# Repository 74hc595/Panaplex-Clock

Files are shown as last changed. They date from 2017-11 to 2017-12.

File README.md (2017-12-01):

# Panaplex Clock

This is a digital clock that uses ["Panaplex" planar gas discharge displays](http://www.tube-tester.com/sites/nixie/trade08-panaplex.htm). Panaplex displays are basically Nixie tubes with a seven-segment cathode arrangement instead of one shaped cathode per digit. And they look *awesome*. The uniform orange glow and lack of gaps between segments make them much more visually appealing than LED displays.

**[Video overview](https://youtu.be/n3AglZmtvWA)**



## Features

- 10-digit display
- Sleek, buttonless enclosure made from laser-cut walnut hardwood and acrylic
- Powered from a 5V USB charger
- Coin cell battery backup keeps time when unplugged
- Two capacitive touch sensors for user input
- Highly accurate oscillator; keeps time within ±2 parts per million (about 1 minute per year)
- 12-hour or 24-hour time display with seconds
- Weekday, month, date, and year display
- Automatic calculation of weekday from month/day/year
- Automatic leap year correction up to 2099
- Automatic daylight saving time correction (US) up to 2099
- Sleep mode: display is normally blanked, and a touch displays the time for 10 seconds before fading out
- Scheduled sleep: for each day of the week, the clock can be configured to be on contiuously, in sleep, or on during one of two configurable time ranges

## Background

"Panaplex" was a trademark of [Burroughs Corporation](http://tmsearch.uspto.gov/bin/showfield?f=doc&state=4810:w635z4.2.1), but on the internet, the term is now used generically to describe planar gas discharge displays made by other manufacturers.

The particular modules used in my clock (the SP-35x series) were introduced by [Sperry's Information Displays Division](https://en.wikipedia.org/wiki/Sperry_Corporation) in the early 1970s. I haven't found an exact date of introduction, but they are listed in this gorgeous [February 1973 Sperry Information Displays Catalog (pdf)](http://www.waynekirkwood.com/images/pdf/Sperry_Information_Displays_Catalog_1973.pdf), which implies they were introduced in 1972 or earlier. Sperry's display division was acquired by [Beckman](https://www.beckman.com/about-us/company-history/company-history-timeline) later in 1973. Babcock acquired the display division from Beckman in [1984](http://www.procureinc.com/manufacturer/Babcock_-_Microsemi/). Babcock was [acquired by Microsemi in 2008](https://www.eetimes.com/document.asp?doc_id=1169534).

These gas discharge displays (also called "plasma displays," though nowadays that term refers to TVs) were used extensively in aviation (as they are readable in bright sunlight) and in many pinball machines starting from the mid-1970s. They are still sold by [Vishay](https://www.vishay.com/displays/plasma/) at exorbitant prices.

## Hardware

I built the clock predominantly out of parts I had on hand. The electronics are constructed on four single-sided PCBs I milled with a desktop CNC machine. Here's a top view:

```
             Display Board              
     ──────────────────────────────     
 Left│                            │Right
 Wing│       ┌───────────┐        │Wing 
Board│       │Logic board│        │Board
     │       └───────────┘        │     
```

- The display board contains the Panaplex displays and the anode drive transistors
- Each "wing board" is mounted at a right angle to the display board and contains a cathode driver chip
- The logic board contains the microcontroller, real-time clock, backup battery, and high voltage power supply

Dave Jones of [EEVblog](eevblog.com) has a great series of videos ([part 1](https://www.youtube.com/watch?v=7uogKucrPks), [part 2](https://www.youtube.com/watch?v=hkbPJONJLfs), [part 3](https://www.youtube.com/watch?v=ggVu_U-CsAk&t=1123s)) where he describes how Nixie tubes can be driven with inexpensive TPIC6B595 open-drain shift registers instead of more expensive/exotic parts designed specifically for high voltage display applications. The [TPIC6B595](http://www.ti.com/product/TPIC6B595) is a cousin of the [74HC595 shift register](https://www.sparkfun.com/products/13699) (and also the namesake of my online handle) with 50V clamping diodes on its eight outputs.

Like Nixie tubes, Panaplex displays require a DC anode voltage of about 160-180 volts to operate. I'm using a [Taylor Electronics 1363](http://www.tayloredge.com/storefront/SmartNixie/PSU/index.html) high voltage supply module to step the 5V input voltage up to about 165-170V.

In addition to requiring a 5V supply, the TPIC6B595 also requires logic high inputs to be at least 4.2V. This meant that I would either have to

- use a microcontroller and real-time clock that could operate from a 5V supply, or
- add a 3.3V regulator and level translation circuitry between the microcontroller and the TPIC6B595s

I decided to go with the former to minimize part count. Looking through the microcontrollers I had on hand, I chose a [PIC16F1508](http://www.microchip.com/wwwproducts/en/PIC16F1508) with 256 bytes of RAM, 4K of ROM, and 18 I/O pins. The [ATtiny461A](http://www.microchip.com/wwwproducts/en/ATtiny461A) was the runner-up, but it only had 15 I/O pins, and the criss-crossed VCC and GND pin arrangement would have made a single-sided board layout difficult. All the ARM chips I had on hand were 3.3V parts, so an 8-bit micro was the only option.

To strike a good balance between pin usage and part count, I ganged the digit anodes together in pairs:

```  
   ┌─────────────┐   
   │   ┌─────┐   │   
┌─┬─┬─┬─┬─┬─┬─┬─┬─┬─┐
│5│4│3│2│1│1│2│3│4│5│
└─┴─┴─┴─┴─┴─┴─┴─┴─┴─┘
 │   │   └─┘   │   │ 
 │   └─────────┘   │ 
 └─────────────────┘ 
```

This arrangement only requires 5 anode drive circuits (10 transistors total and 5 I/O lines). The display is multiplexed by the microcontroller; only 2 digits are ever illuminated at a time, so we need to be able to drive 16 segments at once. For this, I used two TPIC6B595s; one to drive the cathodes of the digits on each half of the display. This led to a compact form factor where the display PCB was no larger than the displays themselves, with each TPIC6B595 on a "wing" board mounted at right angles to the display board.

My favorite real-time clock chip, the [PCF2129AT](https://www.nxp.com/docs/en/data-sheet/PCF2129.pdf), has a recommended 4.2V maximum supply voltage. Rather than push it past its specs, I Amazon Primed a [SparkFun DeadOn RTC breakout board](https://www.sparkfun.com/products/10160). The [DS3234](https://www.maximintegrated.com/en/products/digital/real-time-clocks/DS3234.html) is a highly accurate (±2ppm) clock, but golly gee whiz is it expensive. But, since this was a one-off, and Amazon Prime was the only way I was gonna get a DS3234 within 2 days, I figured it was OK to splurge.

The enclosure design is an homage to the wood-grain Heathkit clocks from the 1970s, like the [GC-1005](http://tubetime.us/index.php/2012/04/). After searching through my parts boxes for some nice buttons and coming up empty-handed, I decided to use capacitive touch pads for user input, which resulted in a very clean design with no protrusions.

## Software

The PIC16F1508 doesn't have any dedicated touch sensing hardware, but I stumbled upon Microchip Application Note [AN1298](http://ww1.microchip.com/downloads/en/AppNotes/01298A.pdf) which describes a technique that uses the built-in analog-to-digital converter and requires no external components. I still don't fully understand how it works (capacitive touch sensing is serious black magic) but it does the job!

Microchip has another app note, [AN1334](http://ww1.microchip.com/downloads/en/AppNotes/00001334B.pdf), that describes a lot of great hardware and software techniques for implementing capacitive touch. By sampling the touch sensor every 64 microseconds and using the slew-rate-limiting algorithm described in that document, I was able to get considerable noise reduction.

When power is first applied, several readings are taken from the two touch sensors to establish a baseline level. It takes 512 samples of a touch sensor to establish whether it is "pressed" or not. If a certain number of those samples deviate sufficiently from the baseline value, the sensor is considered "pressed." Since the touch sensors are read one at a time, the full input state is updated at a rate of 15.26 Hz. Though this figure seems low, I haven't found any issues with responsiveness.

Timer2 drives the display multiplexing, at a rate of 4 kHz. (Each pair of digits is on for 250 microseconds). However, I ran into an issue.

I started out thinking I would strobe the digits sequentially in pairs:

```
. . . . 1 1 . . . .
. . . 2 . . 2 . . .
. . 3 . . . . 3 . .
. 4 . . . . . . 4 .
5 . . . . . . . . 5
. . . . 1 1 . . . .
etc.
```

But I was noticing a [strange blue discharge between neighboring digits](https://pbs.twimg.com/media/DNB2jnqVwAAFHNp.jpg). These blue "streamers" can appear if there is insufficient blanking time between two neighboring digits; the anode with the lower potential will act like a cathode, resulting in a visible blue glow between anodes.

(Interesting aside: where exactly _are_ the anodes? Unlike Nixie tubes, which have visible anode grids in front of the digits, there's nothing like that to be found in Panaplex displays. Well, it turns out that the anodes _are_ in front of the digits, but they're made of [indium tin oxide](https://en.wikipedia.org/wiki/Indium_tin_oxide), which is a _transparent conductor_! How cool is that?)

So, to increase the blanking time between neighboring digits without inserting additional blanking intervals, I strobe the digits in a staggered sequence:

```
. . . . 1 1 . . . .
. . 3 . . . . 3 . .
5 . . . . . . . . 5
. . . 2 . . 2 . . .
. 4 . . . . . . 4 .
. . . . 1 1 . . . .
etc.
```

(No streamers appear between the two central digits because their anodes are tied together and are always on simultaneously.)

Timer0 fires every 64 microseconds, causing a touch sensor to be sampled. After 1024 ticks of Timer0, the input state is updated and one iteration of the main loop is run. As mentioned earlier, this gives the main loop an update rate of 15.26 Hz, which is sufficient for simple animations.

The real-time clock's 1 Hz square wave output is used to tell the PIC when to fetch the new time.

I didn't want to have to manually set the weekday whenever I changed the clock's date. So [Sakamoto's method](https://en.wikipedia.org/wiki/Determination_of_the_day_of_the_week#Sakamoto.27s_methods) is used to determine the day of the week for a given date. By restricting the year to the range 2000-2099 I eliminate the divisions by 100 and 400, which would be expensive as the PIC has no divider. The modulo-7 operation is still required, but I chose to implement it with repeated subtraction rather than use the `%` operator and pull in the large division routines. Plus, the weekday calculation only needs to happen when the user changes the date. The real-time clock takes care of incrementing the weekday at midnight, but has no notion of how weekdays relate to dates.

The table for automatic daylight saving time correction (for the United States only) only requires 1 byte of data per year. For the range of years from 2000-2099, the spring transition can only occur on one of 14 dates, and the fall transition can only occur on one of 13 dates. Thus, all you need to encode daylight saving time data for a year are two 4-bit indexes into a table of month/date pairs.

Since the real-time clock stores its data in [binary-coded decimal format](https://en.wikipedia.org/wiki/Binary-coded_decimal), I try to do as many internal calculations and comparisons in BCD as possible. Converting from BCD to binary representation (i.e. for doing a table lookup) is simple; `(low nibble) + 10*(high nibble)`. The multiplication by 10 can be reduced to left-shift and add operations. Converting from binary to BCD requires division by 10, but the code never actually has to do this.

As for the code itself, it's written in C, and not something I'm particularly proud of. I haven't taken the time to split functions up into logical groups or add comments. The PIC is a nightmare for C, due to its bank-switching scheme and lack of a general-purpose stack. This makes pointer operations (_especially_ function pointer operations) consume considerable ROM space. The 1508's [enhanced mid-range architecture](http://www.microchip.com/stellent/groups/SiteComm_sg/documents/DeviceDoc/en542713.pdf) adds a linear addressing scheme and new instructions for indirect access/jumps, but Microchip's non-FOSS [XC8](http://www.microchip.com/mplab/compilers) is the only compiler that takes advantage of them. The PIC backend for the open-source [SDCC compiler](http://sdcc.sourceforge.net) does not seem to be under active development.

## Operation

Let's call the two touch sensors on top of the clock `L` and `R`. (assuming you're looking at the clock's face.)

### Time display

Normally, the clock displays the time, in the form `HH-MM-SS` (in 24-hour mode) or `HH-MM-SS A`/`HH-MM-SS P` (in 12-hour mode)

At the 26th second of even minutes, the display cycles to show the day of week, month and day for three seconds, then cycles to the full date in `MM-DD-YYYY` format for three seconds, then back to the time display.

Tap `L` or `R` to manually cycle between displays.

Hold `L` to enter the menu (see below).

Hold `R` to turn off the display. The display will fade out. Tap either `L` or `R` to resume normal operation. All timekeeping operates normally when the display is off.

### Menu

The menu is accessed by holding `L` from the time display. Tapping L cycles through various menu items (to be explained in individual sections below):

- Sleep mode on/off/scheduled
- Set time
- Set date
- Set year
- Select 12-hour or 24-hour display
- Automatic daylight saving time correction on/off
- Time separators off/solid/flashing
- Change time separator appearance
- Change date separator appearance
- Set sleep schedule
- Done (tap `R` to exit the menu)

Hold `L` at any time to return to the time display. Tapping `R` either changes the flashing value or enters a submenu.

### Setting the time and date

From the time display, hold `L` to enter the menu. Tap `L` again to advance to the "set time" prompt:

```
SET HH.MM
```

The word `SET` will be flashing. Tap `R` and the hours will flash. Tap or hold `R` to advance the hours. Tap `L` and the minutes will flash. Tap or hold `R` to advance the minutes. Finally, tap `L` one last time to store the new time and reset the seconds to `00`.

At this point, `SET` should be flashing again. Tap `L` to advance to the "set date" prompt:

```
SET MM-DD
```

Tap `R` and the month will flash. Tap or hold `R` to advance the month. Tap `L` and the date will flash. Tap or hold `R` to advance the date. Tapping `L` one last time advances to the "set year" prompt:

```
YEAR YYYY
```

The year should be flashing. Tap or hold `R` to advance the year. Valid years are 2000-2099.

### Selecting 12-hour or 24-hour mode

From the time display, hold `L` to enter the menu. Tap `L` until you arrive at the 12/24-hour prompt:

```
DISP. 12hr  (or)  DISP. 24hr
```

Tap `R` to alternate between 12-hour and 24-hour modes.

### Enabling/disabling daylight saving time correction

From the time display, hold `L` to enter the menu. Tap `L` until you arrive at the daylight saving time prompt:

```
D.S.T. AUTO  (or)  D.S.T. OFF
```

If DST is set to `AUTO` and the current date is currently in daylight saving time, a `+` will illuminate on the left side of the display.

Only US daylight saving time is supported. On the day of the spring transition, the clock will advance `01:59:59 -> 03:00:00`. On the day of the fall transition, the clock will advance `01:59:59 -> 01:00:00`.

**Note:** an ambiguous condition exists when attempting to set the time to `01:00-01:59` on the day of the fall DST transition. The clock does not know if you mean "the hour `01:xx` before the transition" or "the hour `01:xx` after the transition." In this situation, the clock always assumes the former.

### Changing display appearance

The separators ("colons") between hours, minutes, and seconds can be set to either illuminate solidly, flash once per second, or be off entirely.

From the time display, hold `L` to enter the menu. Tap `L` until you arrive at the time separator prompt:

```
SEP. SOLID  (or)  SEP. FLASH  (or)  SEP. OFF
```

Tap `R` to cycle between the options.

Tap `L` again to advance to the time separator style prompt:

```
SEP.STYLE -
```

You have four choices of time separator:

- hyphen `-`
- dot `.`
- pseudo-colon (looks like `=`)
- tall pseudo-colon (top and bottom horizontal segments illuminated)

Tap `R` to cycle between the options.

Tap `L` again to advance to the date separator style prompt:

```
DATESEP. -  (or)  DATESEP. .
```

Tap `R` to select either a hyphen or dot as the separator between month, day, and year.

### Sleep and scheduled sleep

From the time display, hold `L` to enter the menu. The first item allows you to select between three modes:

- `SLEEP OFF`: display always on 24 hours a day
- `SLEEP ON`: display normally off; touch to wake for 10 seconds
- `SLEEP SCH.`: scheduled sleep (customizable per-day asleep/awake time ranges)

Tap `R` to cycle between the options. Additionally, the `+` will illuminate if the clock is currently awake, and the `-` will illuminate if the clock is currently in sleep mode.

To edit the sleep schedule, tap `L` until you arrive at

```
SET SCHED.
```

Tap `R` to enter the schedule submenu:

```
DAYS 1 2
```

The selection `DAYS` will be flashing. Tap `L` to cycle between three selections:

- `DAYS` - select a sleep schedule for each weekday
- `1` - edit Range 1 (see below)
- `2` - edit Range 2

#### Configuring per-day behavior

With `DAYS` flashing, tap `R` to enter

```
Su. _ _ _ _ _ _ _
```

Each character represents a day of the week, Sunday to Saturday. Tap `L` to advance between days, and tap `R` to select an option for each day:

- `_` - display on 24 hours a day
- `1` - display on during the hours of Range 1 and in sleep mode otherwise
- `2` - display on during the hours of Range 2 and in sleep mode otherwise
- `Ξ` - in sleep mode 24 hours a day

Hold `L` to return to the schedule submenu.

#### Editing time ranges

By selecting Range 1 or Range 2 for a given day, the clock can automatically turn the display on and enter sleep at specific times.

From the schedule submenu, tap `L` until either `1` or `2` is flashing, then tap `R` to enter the range editor.

In 24-hour mode, the range editor display looks like

```
1. 09--17
```

In 12-hour mode, the range editor display looks like

```
1. 9A- 5P
```

The first hour should be flashing. This is the time when the display should turn on. Tap or hold `R` to advance the on-hour.

Tap `L` and the second hour should be flashing. This is the time when the clock should go to sleep. Tap or hold `R` to advance the off-hour.

If the on-hour is later than or equal to the off-hour, an apostrophe `'` will appear next to the off-hour:

```
1. 20-03'
```

This means "turn on at 8PM (20:00) and go to sleep at 3AM (03:00) _the next day_."

## Power consupmtion

When the display is active, the clock consumes about 500 mA (2.5 watts). However, there seems to be a large inrush of current when the high voltage supply is turned on; if the power supply can't handle it, the supply voltage may drop low enough to trip the PIC's brown-out reset circuit. This manifests as a delay of about a second when touching to wake from sleep. The PIC is resetting, and the clock always goes through a touch sensor calibration cycle after a reset, which takes about one second.

A high-quality USB power adapter capable of handling at least 1A will prevent this from happening. The Apple 5W Power Adapter (model A1385) works very well. I've seen this happen with cheaper USB adapters that claim to handle 1A.

I have not measured standby current, but my estimate is a few milliamps.

## Conclusion

Total time to project completion was about a month and a half.

Follow me on Twitter for future project updates and random electronics stuff: [@txsector](https://twitter.com/txsector)

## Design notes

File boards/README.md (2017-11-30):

# Panaplex Clock Design Files

The clock is built from four PCBs:

- the display board
- two "wing" boards for the cathode drivers
- the microcontroller board

All board designs are single-sided, as they were designed to be milled onto single-sided FR1 using an [Othermill V2](https://support.bantamtools.com/hc/en-us/articles/115001668853-Othermill-V2-). I'm including the board layouts for completeness; I would **not** recommend fabricating them in their current state, even if you have a desktop CNC mill. In the future I may redo the layouts and get double-sided boards professionally fabricated.

 Some notes:

- Traces and surface-mount components are on the back copper layer. (This is the side that gets milled.)
- Through-hole component footprints (displays, headers, etc.) are on the front "copper" layer. (This is the "blank" side with no copper.)
- The front copper layer is used for wire links and is not intended to be fabricated.
- The wing boards are soldered directly to either side of the display board, at right angles.
- No attention has been paid to silkscreen/soldermask layout.
- The boards were designed to be milled with 1/32" and 1/64" flat endmills. Trace width/spacing was set with these conditions in mind.

In hindsight, milled single-sided FR1 boards were not great for this application. The rapid turnaround time was great, but:

- I tried to make the display board millable using only a 1/32" endmill, which resulted in some traces that were too thin and broke during milling.
- The right-angle joints between the wings and the display board are not structurally sound. Without additional reinforcement, the bonding between the copper and the phenolic substrate becomes the weak point.
- It's *very* easy to lift pads and butcher traces when soldering. I had to do considerable rework during the build process. I completely botched the interconnects between the wing boards and the MCU board and wound up soldering kynar wires directly to the IC leads.
- I forgot to add a proper connector on the display board for the high-voltage supply and had to solder a jumper wire directly to the trace.
- Connections from the 5 anode selects to the drive transistors were left out of the display board schematic. Looking at the board layout, you can see five vias to nowhere. These accept an 0.1" header pin.

## Bill of materials

### Display board

- D1: Beckman SP-355 Panaplex 3 1/2-digit display module. (I haven't found any reference to these online; I pulled mine from some old panel meters.)
- D2, D3: Beckman [SP-353](http://www.industrialalchemy.org/articleview.php?item=20) Panaplex 3-digit display module. From eBay.
- D1, D2, and D3 are socketed in [Mill-Max 0566-2-15-15-21-27-10-0 pin receptacles](https://www.mouser.com/Search/ProductDetail.aspx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). They are open on both sides to accomodate pins of arbitrary length.
- Q1, Q3, Q5, Q7, Q9: MMBTA92 high-voltage PNP transistors
- Q2, Q4, Q6, Q8, Q10: MMBTA42 high-voltage NPN transistors
- All resistors 1206, 1/4 watt

### Wings

- U1, U2: TPIC6B595DWRG4 power logic 8-bit shift registers
- All resistors 1206, 1/4 watt

### Microcontroller board

- U1: PIC16F1508-I/P
- U2: [SparkFun DeadOn DS3234 breakout board](https://www.sparkfun.com/products/10160) (I used a breakout board because I could get one with free 2-day shipping on Amazon, which wouldn't have been possible if I had ordered the bare DS3234s.)
- J5: [Taylor Electronics 1363](http://www.tayloredge.com/storefront/SmartNixie/PSU/index.html) high voltage power supply since I have a couple on hand. I desoldered the straight dual-row header and replaced it with a right-angle header to make the design more compact.
- C1, R1, R2: resistors and capacitors 1206. All resistors 1/4 watt.
- C2: bodged-in 470uF electrolytic capacitor. Switching on the high-voltage supply can cause the 5V supply to drop for a brief period, which would cause the PIC to brown out.

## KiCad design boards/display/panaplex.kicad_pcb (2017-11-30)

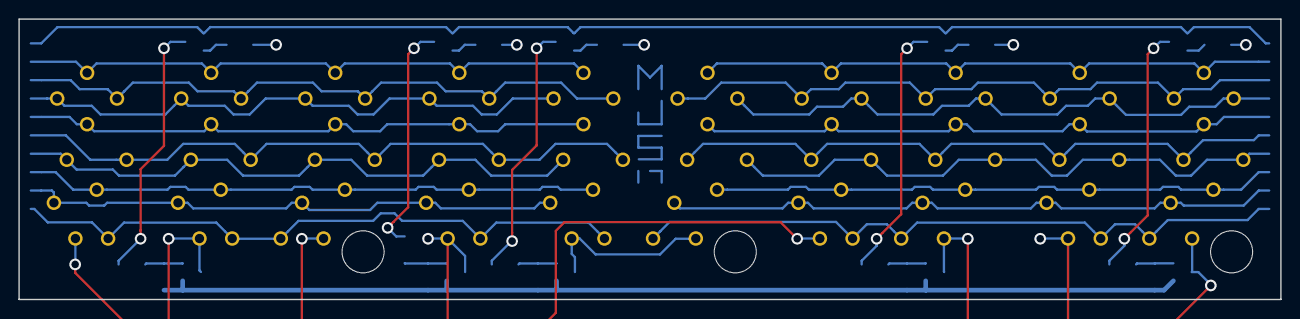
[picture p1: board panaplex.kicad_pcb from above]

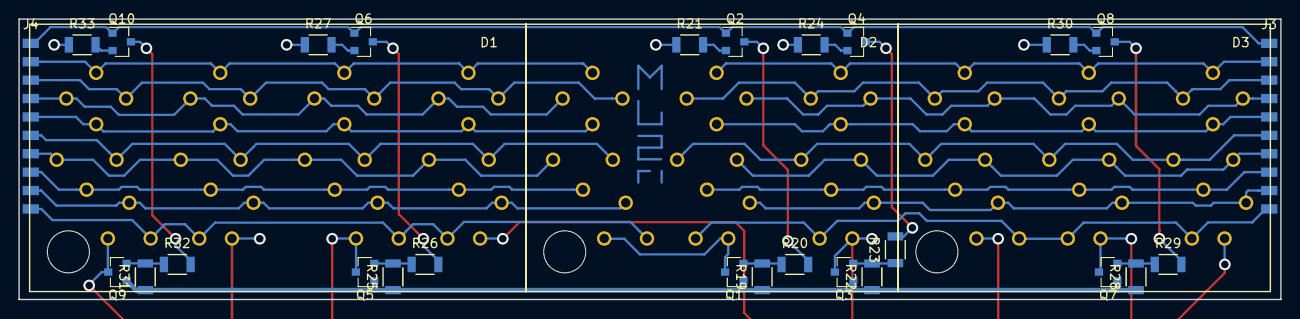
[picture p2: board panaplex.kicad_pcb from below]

Board: 2 copper layers, 137.2 x 30.5 mm, 30 parts (30 on the bottom side), 40 nets.

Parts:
D1: SP-355; Panaplex_SP-355_PinSockets
D2, D3: SP-353; Panaplex_SP-353_PinSockets
J3, J4: CONN_01X10; Pads_1x10_Pitch2.00mm_SMD
Q1, Q3, Q5, Q7, Q9: MMBTA92; SOT-23_Flipped
Q2, Q4, Q6, Q8, Q10: MMBTA42; SOT-23_Flipped
R19, R22, R25, R28, R31: 100k; R_1206
R20, R23, R26, R29, R32: 470k; R_1206
R21, R24, R27, R30, R33: 33k; R_1206

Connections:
+170V: Q1.2, Q3.2, Q5.2, Q7.2, Q9.2, R19.1, R22.1, R25.1, R28.1, R31.1
/AN0: D2.B9, D2.C9, Q1.3
/AN1: D1.A9, D2.A9, Q3.3
/AN2: D1.B9, D3.C9, Q5.3
/AN3: D1.C9, D3.B9, Q7.3
/AN4: D1.D9, D3.A9, Q9.3
/K0A: D2.A1, D2.B1, D3.A1, D3.B1, D3.C1, J3.2
/K0B: D2.A2, D2.B2, D3.A2, D3.B2, D3.C2, J3.4
/K0C: D2.A3, D2.B3, D3.A3, D3.B3, D3.C3, J3.7
/K0D: D2.A4, D2.B4, D3.A4, D3.B4, D3.C4, J3.8
/K0E: D2.A5, D2.B5, D3.A5, D3.B5, D3.C5, J3.6
/K0F: D2.A6, D2.B6, D3.A6, D3.B6, D3.C6, J3.3
/K0G: D2.A7, D2.B7, D3.A7, D3.B7, D3.C7, J3.5
/K0P: D2.A8, D2.B8, D3.A8, D3.B8, D3.C8, J3.9
/K1A: D1.A1, D1.B1, D1.C1, D1.D1, D2.C1, J4.2
/K1B: D1.A2, D1.B2, D1.C2, D1.D2, D2.C2, J4.3
/K1C: D1.A3, D1.B3, D1.C3, D1.D3, D2.C3, J4.6
/K1D: D1.A4, D1.B4, D1.C4, D1.D4, D2.C4, J4.8
/K1E: D1.A5, D1.B5, D1.C5, D1.D5, D2.C5, J4.7
/K1F: D1.A6, D1.B6, D1.C6, D1.D6, D2.C6, J4.4
/K1G: D1.A7, D1.B7, D1.C7, D1.D7, D2.C7, J4.5
/K1P: D1.A8, D1.B8, D1.C8, D1.D8, D2.C8, J4.9
/KA0: D2.A10, D2.B10, D3.A10, D3.B10, D3.C10, J3.10
/KA1: D1.A10, D1.B10, D1.C10, D1.D10, D2.C10, J4.10
GND: J3.1, J4.1, Q2.2, Q4.2, Q6.2, Q8.2, Q10.2
unnamed: Q1.1, R19.2, R20.1
unnamed: Q2.1, R21.2
unnamed: Q2.3, R20.2
unnamed: Q3.1, R22.2, R23.1
unnamed: Q4.1, R24.2
unnamed: Q4.3, R23.2
unnamed: Q5.1, R25.2, R26.1
unnamed: Q6.1, R27.2
unnamed: Q6.3, R26.2
unnamed: Q7.1, R28.2, R29.1
unnamed: Q8.1, R30.2
unnamed: Q8.3, R29.2
unnamed: Q9.1, R31.2, R32.1
unnamed: Q10.1, R33.2
unnamed: Q10.3, R32.2

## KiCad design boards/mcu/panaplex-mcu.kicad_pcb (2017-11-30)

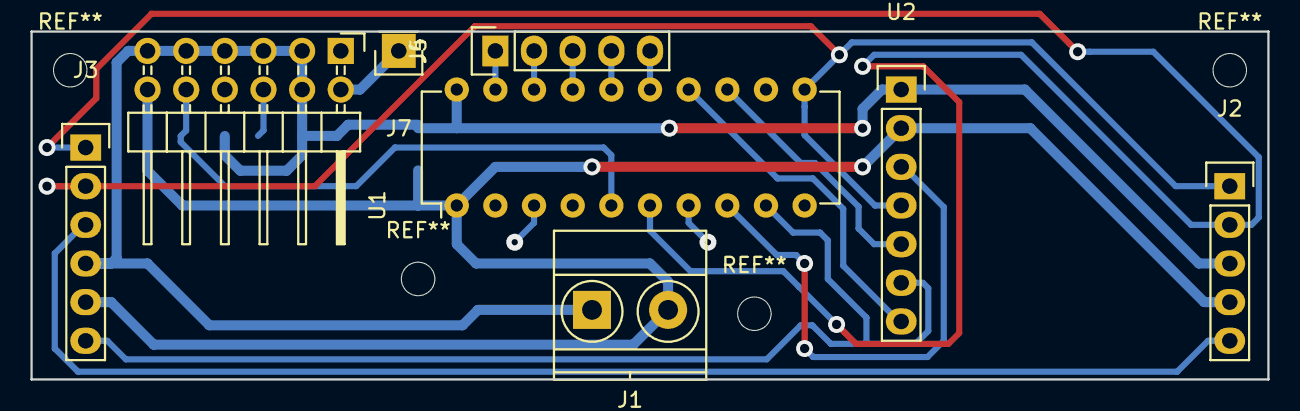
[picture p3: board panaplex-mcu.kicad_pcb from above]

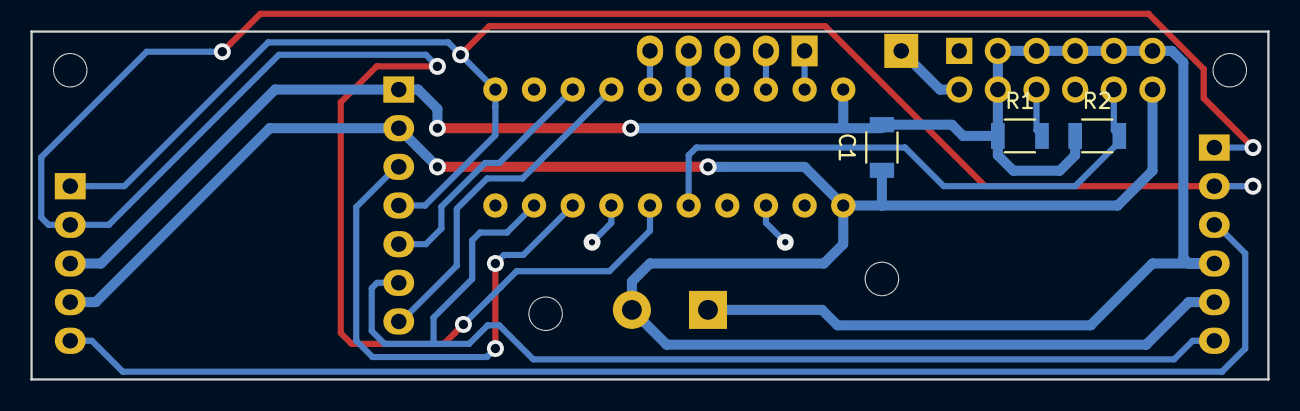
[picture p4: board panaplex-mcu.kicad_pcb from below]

Board: 2 copper layers, 81.3 x 22.9 mm, 11 parts (3 on the bottom side), 17 nets.

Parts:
C1: 0.1uF; C_1206
J1: Screw_Terminal_1x02; TerminalBlock_Pheonix_MKDS1.5-2pol
J2: To Right Wing; Pin_Header_Straight_1x05
J3: To Left Wing; Pin_Header_Straight_1x06
J4: Anode Selects; Pin_Header_Straight_1x05
J5: Tayloredge 1363; Pin_Header_Angled_2x06
J7: HV Out; Pin_Header_Straight_1x01
R1: 68k; R_1206
R2: 100k; R_1206
U1: PIC16F1508-I/P; DIP-20_W7.62mm
U2: SparkFun DeadOn RTC (DS3234); Pin_Header_Straight_1x07

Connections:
/ANSEL0: J4.1, U1.19
/ANSEL1: J4.2, U1.18
/ANSEL2: J4.3, U1.17
/ANSEL3: J4.4, U1.16
/ANSEL4: J4.5, U1.15
/DCASC: J2.5, J3.3
/HV: J5.2, J7.1
/HV_EN: J5.10, R2.2, U1.5
/LATCH: J2.2, J3.1, U1.6
/MISO: U1.13, U2.5
/MOSI: J3.6, U1.9, U2.6
/SCK: J2.1, J3.2, U1.11, U2.4
/SQW: U1.8, U2.3
/~RTC_SS: U1.14, U2.7
GND: C1.2, J1.1, J2.3, J3.4, J5.3, J5.4, J5.5, J5.7, J5.9, J5.11, R1.1, R2.1, U1.20, U2.1
unnamed: J5.6, R1.2
VCC: C1.1, J1.2, J2.4, J3.5, J5.12, U1.1, U2.2

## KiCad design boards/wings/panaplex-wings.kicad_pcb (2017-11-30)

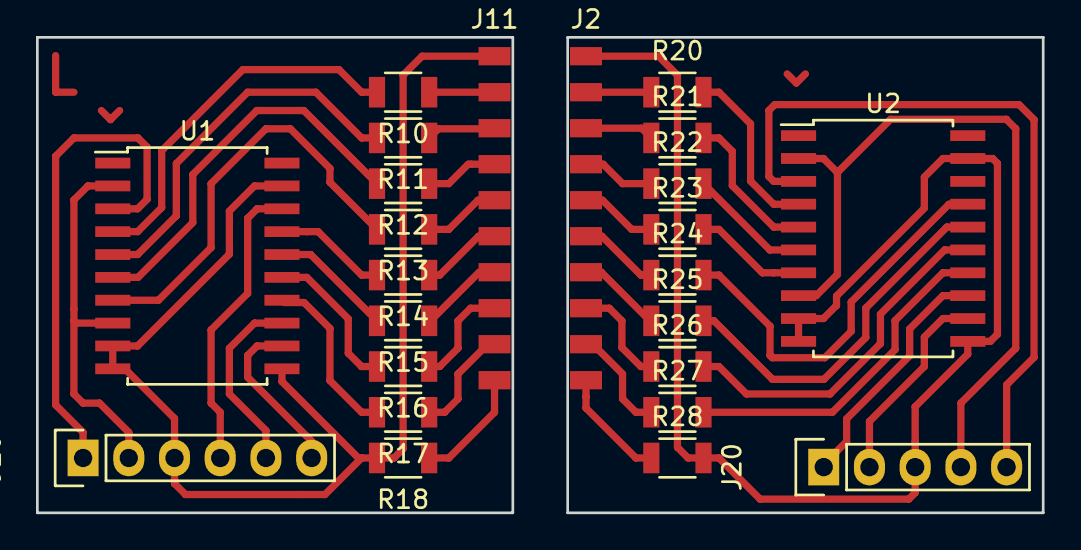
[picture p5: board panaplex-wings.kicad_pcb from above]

Board: 2 copper layers, 55.9 x 26.4 mm, 24 parts (0 on the bottom side), 43 nets.

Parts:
J2, J11: CONN_01X10; Pads_1x10_Pitch2.00mm_SMD
J10: CONN_01X06; Pin_Header_Straight_1x06
J20: CONN_01X05; Pin_Header_Straight_1x05
R10, R11, R12, R13, R14, R15, R16, R20, R21, R22, R23, R24, R25, R26: 22k; R_1206
R17, R27: 220k; R_1206
R18, R28: 330k; R_1206
U1, U2: TPIC6B595; SOIC-20W_7.5x12.8mm_Pitch1.27mm

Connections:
/K0A: R10.2, U1.4
/K0B: R12.2, U1.6
/K0C: R15.2, U1.16
/K0D: R16.2, U1.15
/K0E: R14.2, U1.17
/K0F: R11.2, U1.5
/K0G: R13.2, U1.7
/K0P: R17.2, U1.14
/K1A: R20.2, U2.4
/K1B: R22.2, U2.6
/K1C: R25.2, U2.16
/K1D: R26.2, U2.15
/K1E: R24.2, U2.17
/K1F: R21.2, U2.5
/K1G: R23.2, U2.7
/K1P: R27.2, U2.14
GND: J2.1, J10.3, J11.1, J20.3, R18.2, R28.2, U1.9, U1.10, U1.11, U1.19, U2.9, U2.10, U2.11, U2.19
unnamed: J2.2, R20.1
unnamed: J2.3, R21.1
unnamed: J2.4, R22.1
unnamed: J2.5, R23.1
unnamed: J2.6, R24.1
unnamed: J2.7, R25.1
unnamed: J2.8, R26.1
unnamed: J2.9, R27.1
unnamed: J2.10, R28.1
unnamed: J10.1, U1.3
unnamed: J10.4, U1.18
unnamed: J10.5, U1.13
unnamed: J10.6, U1.12
unnamed: J11.2, R10.1
unnamed: J11.3, R11.1
unnamed: J11.4, R12.1
unnamed: J11.5, R13.1
unnamed: J11.6, R14.1
unnamed: J11.7, R15.1
unnamed: J11.8, R16.1
unnamed: J11.9, R17.1
unnamed: J11.10, R18.1
unnamed: J20.1, U2.13
unnamed: J20.2, U2.12
unnamed: J20.5, U2.3
VCC: J10.2, J20.4, U1.2, U1.8, U2.2, U2.8

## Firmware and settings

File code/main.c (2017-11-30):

/**
 *
 * Panaplex clock
 *
 * Matt Sarnoff (msarnoff.org)
 * November 22, 2017
 *
 * Features:
 * - 10-digit gas discharge display
 * - DS3234 real-time clock with battery backup
 * - Time display with seconds
 * - Date, month, year, and day of week displays
 * - Sleep mode with display fade in/out effects
 * - Automatic daylight saving time correction (US only) up to 2099
 * - Leap year correction up to 2099
 * - Customizable display:
 *   - 12- or 24-hour format
 *   - Choice of colon "separators" with optional flashing
 *   - Choice of date separators (dashes or dots)
 * - Two capacitive touch sensors
 * - Menu interface
 * - Can be set to turn on/off at scheduled times
 *   - Selectable schedule for each weekday
 *   - Display can be on continuously 24 hours a day, off for 24 hours a day
 *     (activated by the touch sensors), or on during a choice of two time spans
 *
 * I have not taken the time to split the code into multiple files or add
 * decent comments.
 */

// CONFIG1
#pragma config FOSC = INTOSC    // Oscillator Selection Bits (INTOSC oscillator: I/O function on CLKIN pin)
#pragma config WDTE = OFF       // Watchdog Timer Enable (WDT disabled)
#pragma config PWRTE = OFF      // Power-up Timer Enable (PWRT disabled)
#pragma config MCLRE = OFF      // MCLR Pin Function Select (MCLR/VPP pin function is digital input)
#pragma config CP = OFF         // Flash Program Memory Code Protection (Program memory code protection is disabled)
#pragma config BOREN = ON       // Brown-out Reset Enable (Brown-out Reset enabled)
#pragma config CLKOUTEN = OFF   // Clock Out Enable (CLKOUT function is disabled. I/O or oscillator function on the CLKOUT pin)
#pragma config IESO = OFF       // Internal/External Switchover Mode (Internal/External Switchover Mode is disabled)
#pragma config FCMEN = ON       // Fail-Safe Clock Monitor Enable (Fail-Safe Clock Monitor is enabled)

// CONFIG2
#pragma config WRT = OFF        // Flash Memory Self-Write Protection (Write protection off)
#pragma config STVREN = ON      // Stack Overflow/Underflow Reset Enable (Stack Overflow or Underflow will cause a Reset)
#pragma config BORV = LO        // Brown-out Reset Voltage Selection (Brown-out Reset Voltage (Vbor), low trip point selected.)
#pragma config LPBOR = OFF      // Low-Power Brown Out Reset (Low-Power BOR is disabled)
#pragma config LVP = OFF        // Low-Voltage Programming Enable (High-voltage on MCLR/VPP must be used for programming)

#include <xc.h>
#include <stdint.h>

#include "io_macros.h"
#include "bit_macros.h"
#include "pin_assignments.h"
#include "dst_dates.h"
#include "display_macros.h"

#define _XTAL_FREQ 16000000

//void putch(unsigned char ch) {
//  while (!TXSTAbits.TRMT) {}
//  TXREG = ch;
//}

static inline void io_init(void)
{
  ALL_OUTPUTS = 0;

  pin_digital(ANODE0);
  pin_digital(ANODE1);
  pin_digital(ANODE2);
  pin_digital(ANODE3);
  pin_digital(ANODE4);
  pin_digital(MOSI);
  pin_digital(nRTC_SS);
  pin_digital(MISO);
  pin_digital(SQW);
  pin_analog(SENSE1);
  pin_analog(SENSE2);

  /* Slave selects are active low */
  pin_high(nDISP_SS);
  pin_high(nRTC_SS);
  
  pin_output(ANODE0);
  pin_output(ANODE1);
  pin_output(ANODE2);
  pin_output(ANODE3);
  pin_output(ANODE4);
  pin_output(MOSI);
  pin_output(SCK);
  pin_output(nRTC_SS);
  pin_output(nDISP_SS);
  pin_input(MISO);
  pin_input(SQW);
  pin_output(HV_EN);
  pin_input(SENSE1);
  pin_input(SENSE2);
}


static inline void osc_init(void)
{
  /* enable high frequency internal oscillator at 16 MHz */
  OSCCON = 0b01111010;
  while (!(OSCSTATbits.HFIOFS && OSCSTATbits.HFIOFR)) {}
}


static inline void hv_on(void)
{
  pin_high(HV_EN);
}


static void hv_off(void)
{
  pin_low(HV_EN);
}


static inline void spi_init(void)
{
  SSPCONbits.SSPM = 1; /* SPI Master mode, clock = Fosc/16 (1 MHz) */
  /* SPI mode 3, compatible with both TPIC6B595 and DS3234 */
  CKP = 1;
  CKE = 0; /* CKE is the inverse of what's usually called "CPHA" */
  SSPEN = 1;
}


static uint8_t spi_out(uint8_t n)
{
  do {
    WCOL = 0;
    SSPBUF = n;
  } while (WCOL); 
  while (!BF) {}
  return SSPBUF;
}


static inline void adc_init(void)
{
  ADFM = 1; /* Right-justified; bits 15:10 of result always 0 */
}


static inline void mux_timer_init(void)
{
  /* use Timer2 to drive digit multiplexing. */
  T2CONbits.T2CKPS = 0b01; /* 1/4 prescaler */
  PR2 = 250; /* 4 KHz. Each anode is on for ~250us */
  TMR2IE = 1;
  TMR2ON = 1;
}


static inline void mux_start(void)
{
  PEIE = 1;
  GIE = 1;
}


#define BRIGHTNESS_MAX  16
#define BRIGHTNESS_MIN  0

static uint8_t display[NUM_DIGITS] = {0};
static uint8_t fade_counter = 0;
static uint8_t fade_level = 0; /* fade in on power-up */
static uint8_t fade_target = BRIGHTNESS_MAX;
static void display_digits(uint8_t low_digit, uint8_t high_digit)
{
  pin_low(nDISP_SS);
  if ((fade_counter & 15) < fade_level) {
    spi_out(display[low_digit]);
    uint8_t n = display[high_digit];
    spi_out(SEGMENT_SWAP(n));
  } else {
    spi_out(0);
    spi_out(0);
  }
  pin_high(nDISP_SS);
}


static uint8_t mux_digit = 0;
static volatile bit blanked = 0;
static inline void timer2_interrupt(void)
{
  if (!TMR2IF) { return; }
  TMR2IF = 0;
  /* all anodes off */
  pins_low(ANODE012_PORT, ANODE012_PINS);
  pins_low(ANODE34_PORT, ANODE34_PINS);
  if (blanked || pin_is_low(nRTC_SS)) {
    return;
  }

  switch (mux_digit++) {
    /* Stagger the digits to prevent blue "streamers" due to insufficient */
    /* interdigit blanking time between neighboring digits. */
    case 0:
      display_digits(4,5);
      pin_high(ANODE0);
      return;
    case 1:
      display_digits(2,7);
      pin_high(ANODE2);
      return;
    case 2:
      display_digits(0,9);
      pin_high(ANODE4);
      return;
    case 3:
      display_digits(3,6);
      pin_high(ANODE1);
      return;
    case 4:
      display_digits(1,8);
      pin_high(ANODE3);
      mux_digit = 0;
      fade_counter++;
      return;
  }
}


static const uint8_t bcd_to_segments_left_half[16] = {
  c_0, c_1, c_2, c_3, c_4, c_5, c_6, c_7,
  c_8, c_9, 0,   0,   0,   0,   0,   0
};


static void display_clear(void)
{
  display[0] = 0; display[1] = 0; display[2] = 0; display[3] = 0; display[4] = 0;
  display[5] = 0; display[6] = 0; display[7] = 0; display[8] = 0; display[9] = 0;
}


static void set_bcd_byte(uint8_t pos, uint8_t byte)
{
  display[pos] = bcd_to_segments_left_half[byte >> 4];
  display[pos+1] = bcd_to_segments_left_half[byte & 0x0F];
}


typedef uint8_t bcd;
typedef uint16_t bcd2;

static bcd bcd_increment(bcd n) { return n + (((n & 0xF) == 9) ? 7 : 1); }
static bcd bcd_decrement(bcd n) { return n - (((n & 0xF) == 0) ? 7 : 1); }

static bcd increment_hour(bcd hr)                      { return (hr == 0x23) ? 0x00 : bcd_increment(hr); }
static bcd increment_minute(bcd min)                   { return (min == 0x59) ? 0x00 : bcd_increment(min); }
static bcd increment_month(bcd month)                  { return (month == 0x12) ? 0x01 : bcd_increment(month); }
static bcd increment_date(bcd date, bcd days_in_month) { return (date >= days_in_month) ? 0x01 : bcd_increment(date); }
static bcd increment_year(bcd year)                    { return (year == 0x99) ? 0x00 : bcd_increment(year); }

static bcd decrement_hour(bcd hr)                      { return (hr == 0x00) ? 0x23 : bcd_decrement(hr); }
static bcd decrement_minute(bcd min)                   { return (min == 0x00) ? 0x59 : bcd_decrement(min); }
static bcd decrement_month(bcd month)                  { return (month == 0x01) ? 0x12 : bcd_decrement(month); }
static bcd decrement_date(bcd date, bcd days_in_month) { return (date == 0x01) ? days_in_month : bcd_decrement(date); }
static bcd decrement_year(bcd year)                    { return (year == 0x00) ? 0x99 : bcd_decrement(year); }

/* Fast multiplication by 10 by adding (n<<1)+(n<<3). */
static uint8_t times10(uint8_t n)
{
  n <<= 1;
  uint8_t times2 = n;
  n <<= 2;
  return n+times2;  
}


static bcd leading_zero_suppressed(bcd n)
{
  return (n >= 0x10) ? n : n|0xF0; /* blank */
}


static uint8_t bcd_to_byte(bcd n)
{
  return times10(n >> 4) + (n & 0xF);
}


/* Returns 1 if the 2-digit BCD year is a leap year. */
/* Will only work for the range 2000-2099. (2100 is not a leap year) */
static bit is_leap_year(bcd year)
{
  year = bcd_to_byte(year);
  return (year & 3) == 0; /* leap year if divisble by 4 */
}


static const bcd days_in_month_table[] = {
  0x31, 0x28, 0x31, 0x30, 0x31, 0x30, 0x31, 0x31, 0x30, 0x31, 0x30
};

static bcd days_in_month(bcd month, uint8_t leap_year)
{
  /* let's just get this out of the way */
  if (leap_year && month == 2) { return 0x29; }
  /* hasty bcd to binary conversion */
  if (month & 0x10) { month -= 6; }
  if (month >= 11) { return 0x31; }
  return days_in_month_table[month-1];
}


static bcd to_12_hour(bcd hour)
{
  if (hour == 0x00) { /* midnight */
    return 0x12;
  } else if (hour <= 0x12) {
    return hour;
  } else {
    return hour - ((hour == 0x20 || hour == 0x21) ? 24 : 18);
  }
}


static uint8_t am_pm_indicator_for_hour(bcd hour_24)
{
  return (hour_24 < 0x12) ? c_A : c_P; /* "A"/"P" indicator */
}


/* Sunday=1, Monday=2, ..., Saturday=7 */
static uint8_t weekday_for_date(bcd month, bcd date, bcd year)
{
  /* Sakamoto's method. */
  /* Not fast, but it only needs to be called when the user sets the date. */
  static const uint8_t t[12] = {0, 3, 2, 5, 0, 3, 5, 1, 4, 6, 2, 4};
  month = bcd_to_byte(month);
  date = bcd_to_byte(date);
  uint16_t full_year = 2000 + bcd_to_byte(year);
  full_year -= (month < 3);
  /* If year is restricted to the range 2000-2099, */
  /* the (y/100) term is always 20 and the (y/400) term is always 5. */
  uint16_t sum = full_year + (full_year>>2) - 20 + 5 + t[month-1] + date;
  /* Sum will be in the range [2484, 2645] inclusive. */
  /* Subtract 2484. Add 6 because (2484%7)==6. */
  uint8_t day = sum - 2478;
  /* Compute mod 7 without using the mod operator, which increases program size. */
  while (day >= 7) { day -= 7; }
  return day+1;
}


static void rtc_set_register(uint8_t addr, uint8_t value)
{
  while (pin_is_low(nDISP_SS)) {}
  pin_low(nRTC_SS);
  spi_out(0x80|addr);
  spi_out(value);
  pin_high(nRTC_SS);
}


static uint8_t rtc_get_register(uint8_t addr)
{
  while (pin_is_low(nDISP_SS)) {}
  pin_low(nRTC_SS);
  spi_out(addr);
  uint8_t value = spi_out(0);
  pin_high(nRTC_SS);
  return value;
}


struct ds3234_time {
  union {
    struct {
      unsigned int seconds:8;
      unsigned int minutes:8;
      unsigned int hour:6;
      unsigned int mode_12hr:1;
      unsigned int :1;
      unsigned int weekday:3;
      unsigned int :5;
      unsigned int date:8;
      unsigned int month:5;
      unsigned int :2;
      unsigned int century:1;
      unsigned int year:8;
    };
    uint8_t bytes[7];
  };
};
/* Globally readable time. Updated once per second. */
static struct ds3234_time current_time;
static bit need_time_update = 0;
static bit need_time_redraw = 0;
/* Alarm 2 flag. Set daily at 02:00. Used to check for DST transitions. */
static bit a2f = 0;

static void update_sleep_state(void);
static void rtc_get_time(void)
{
  while (pin_is_low(nDISP_SS)) {}
  pin_low(nRTC_SS);
  spi_out(0); /* set register to 0 */
  for (uint8_t i = 0; i < sizeof(current_time); i++) {
    current_time.bytes[i] = spi_out(0); /* clock out bytes */
  }
  pin_high(nRTC_SS);
  need_time_update = 0;
  need_time_redraw = 1;
  a2f = (rtc_get_register(0x0F) & 0x2) != 0;
  update_sleep_state();
}


static void rtc_set_time_full(void)
{
  current_time.weekday = weekday_for_date(current_time.month, current_time.date, current_time.year);
  while (pin_is_low(nDISP_SS)) {}
  pin_low(nRTC_SS);
  spi_out(0x80); /* set register to 0 */
  for (uint8_t i = 0; i < sizeof(current_time); i++) {
    spi_out(current_time.bytes[i]); /* clock out bytes */
  }
  pin_high(nRTC_SS);
  rtc_get_time();
}


static void date_add_hour(void)
{
  /* Straightforward. Increment the smallest component. If it wraps around, */
  /* increment the next larger component, etc. */
  if ((current_time.hour = increment_hour(current_time.hour))           != 0x00) { goto done; }
  uint8_t max_date = days_in_month(current_time.month, is_leap_year(current_time.year));
  if ((current_time.date = increment_date(current_time.date, max_date)) != 0x01) { goto done; }
  if ((current_time.month = increment_month(current_time.month))        != 0x01) { goto done; }
  current_time.year = increment_year(current_time.year);
done:
  rtc_set_time_full();
}
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
void main(void)
{
  io_init();
  osc_init();
  spi_init();
  rtc_init();
  adc_init();
  mux_timer_init();

  /* startup delay so we don't rapidly toggle HV_EN during programming */
  __delay_ms(500);
  hv_on();     /* danger, danger! high voltage! when we touch, when we kiss! */
  mux_start(); /* enables interrupts */

  /* calibrate touch sensors; do this after enabling the HV supply so */
  /* environmental noise is taken into account */
  touch_sensor_calibrate(&ts1);
  touch_sensor_calibrate(&ts2);
  touch_loop_start();

  /* force initial time update */
  rtc_get_time();
  /* if we start up in scheduled sleep, don't go to sleep immediately */
  sleep_now = 0;

  current_mode->init();

  while (1) {
    while (!boop) {}
    boop = 0;
    touch1_events = touch_sensor_update_and_get_events(&ts1);
    touch2_events = touch_sensor_update_and_get_events(&ts2);
    rtc_poll();
    
    /* The flash counter increments every frame. */
    flash_count++;
    /* The timeout counter decrements every frame, but is paused if a */
    /* touch sensor is pressed. */
    if (timeout > 0 && !ts1.state && !ts2.state) {
      timeout--;
    }

    /* Handle fades. */
    if (fade_level < fade_target) {
      fade_level++;
    } else if (fade_level > fade_target) {
      fade_level--;
    }
 
    current_mode->update();
    if (next_mode != current_mode) {
      current_mode = next_mode;
      current_mode->init();
      /* Redraw screen without processing any events */
      touch1_events = touch2_events = 0;
      current_mode->update();
    }

    if (ts1.state) { set_bits(display[0], sA); } else { clear_bits(display[0], sA); }
    if (ts2.state) { set_bits(display[0], sG); } else { clear_bits(display[0], sG); }
 }
}



/**** Main display drawing routines ****/

static const uint8_t time_separators[4] = {
  sG,    /* middle dash */
  sP,    /* dot */
  sD|sG, /* pseudo-colon */
  sA|sD, /* tall pseudo-colon */
};


static uint8_t weekday_abbrs[8][4] = {
  { 0, 0, 0, 0 },
  { 0,   c_S, c_u, c_n|sP }, /* "Sun." */
  { c_1, c_N, c_o, c_n|sP }, /* "Mon." */
  { 0,   c_7, c_u, c_e|sP }, /* "Tue." */
  { c_1, c_J, c_e, c_d|sP }, /* "Wed." */
  { 0,   c_7, c_h, c_u|sP }, /* "Thu." */
  { 0,   c_F, c_r, c_i|sP }, /* "Fri." */
  { 0,   c_S, c_a, c_t|sP }, /* "Sat." */
};


static void time_draw(void)
{
 if (need_time_redraw) {
    if (current_settings.display_12hr) {
      uint8_t hour = to_12_hour(current_time.hour);
      set_bcd_byte(0, leading_zero_suppressed(hour));
      set_bcd_byte(3, current_time.minutes);
      set_bcd_byte(6, current_time.seconds);
      display[8] = 0;
      display[9] = am_pm_indicator_for_hour(current_time.hour);
    } else {
      display[0] = 0;
      set_bcd_byte(1, current_time.hour);
      set_bcd_byte(4, current_time.minutes);
      set_bcd_byte(7, current_time.seconds);
      display[9] = 0;
    }
    need_time_redraw = 0;
  }

  if (current_settings.time_sep_mode & 1) {
    uint8_t sep = (!(current_settings.time_sep_mode & 2) || pin_is_low(SQW)) ? time_separators[current_settings.time_sep_style] : 0;
    if (current_settings.display_12hr) {
      display[2] = display[5] = sep;
    } else {
      display[3] = display[6] = sep;
    }
  }
}


static void weekday_draw(void)
{
  if (need_time_redraw) {
    uint8_t *wkd = weekday_abbrs[current_time.weekday];
    display[0] = wkd[0];
    display[1] = wkd[1];
    display[2] = wkd[2];
    display[3] = wkd[3];
    display[4] = 0;
    set_bcd_byte(5, leading_zero_suppressed(current_time.month));
    set_bcd_byte(8, current_time.date);
  }
  if (current_settings.date_sep_style == 0) {
    display[7] = sG;
  } else {
    display[7] = 0;
    display[6] |= sP;
  }
}


static void date_draw(void)
{
  if (need_time_redraw) {
    set_bcd_byte(0, leading_zero_suppressed(current_time.month));
    set_bcd_byte(3, current_time.date);
    set_bcd_byte(6, 0x20);
    set_bcd_byte(8, current_time.year);
  }
  if (current_settings.date_sep_style == 0) {
    display[2] = display[5] = sG;
  } else{
    display[1] |= sP;
    display[2] = 0;
    display[4] |= sP;
    display[5] = 0;
  }
}



/**** Main display input handling ****/

static display_update_common(const struct mode *tap_next_mode, void (*anim_draw_fn)(void))
{
  wake_now = 0;
  if (fade_level == 0) {
    display_cycling = 0;
    next_mode = &off;
    return;
  }

  if (TOUCH2_HOLD || sleep_timer >= 154 || sleep_now) {
    /* Begin fade out; power off when display is blank. */
    fade_target = 0;
  }

  if (TOUCH1_HOLD) {
    display_cycling = 0;
    next_mode = &FIRST_MENU_ITEM;
    return;
  } else if (TOUCH1_TAP || TOUCH2_TAP) {
    display_cycling = 0;
    next_mode = tap_next_mode;
    return;
  } else if (TIMEOUT) {
    if (display_cycling) {
      animator_dest = tap_next_mode;
      animator_draw_fn = anim_draw_fn;
      next_mode = &animate;
    } else {
      next_mode = tap_next_mode;
    }
    return;
  }

  /* Advance sleep timer if we're in sleep mode */
  /* and there is no user input. */
  if (sleep && ts1.state == 0 && ts2.state == 0) {
    sleep_timer++;
  }
}



/**** Main display init/update callbacks ****/

static void time_display_init(void)
{
  display_clear();
  need_time_redraw = 1;
  display_cycling = 0;
  timeout = 0;
  sleep_timer = 0;
}


static void time_display_update(void)
{
  display_update_common(&weekday_display, weekday_draw);

  /* At the 26-second mark of even minutes, do an animated transition and */
  /* show the date. */
  if (current_time.seconds == 0x26 && (current_time.minutes & 1) == 0) {
    display_cycling = 1;
    animator_dest = &weekday_display;
    animator_draw_fn = weekday_draw;
    next_mode = &animate;
    return;
  }

  time_draw();
}


static void date_display_init(void)
{
  display_clear();
  need_time_redraw = 1;
  timeout = 47; /* 3 seconds */
}


static void weekday_display_update(void)
{
  if (TOUCH1_PRESS) { timeout = 47; }
  display_update_common(&date_display, date_draw);
  weekday_draw();
}


static void date_display_update(void)
{
  if (TOUCH1_PRESS) { timeout = 47; }
  display_update_common(&time_display, time_draw);
  date_draw();
}


static void animator_init(void)
{
  timeout = 15;
}


static void animator_update(void)
{
  uint8_t t = timeout & 7;
  uint8_t mask = sD;
  if (t <= 6) { mask |= sE; }
  if (t <= 5) { mask |= sC; }
  if (t <= 4) { mask |= sG; }
  if (t <= 3) { mask |= sF; }
  if (t <= 2) { mask |= sB; }
  if (t <= 1) { mask |= sA; }
  if (timeout >= 8) {
    for (uint8_t i = 0; i < NUM_DIGITS; i++) {
      display[i] |= mask;
    }
  } else {
    need_time_redraw = 1;
    animator_draw_fn();
    for (uint8_t i = 0; i < NUM_DIGITS; i++) {
      display[i] |= ((~mask) & (~sP));
    }
  }

  if (TIMEOUT) {
    next_mode = animator_dest;
  }
}


static void off_update(void)
{
  sleep_now = 0;
  /* Tapping either sensor powers the display back on. */
  if (TOUCH1_TAP || TOUCH2_TAP || wake_now) {
    hv_on();
    fade_target = BRIGHTNESS_MAX;
    fade_level = 1;
    next_mode = &time_display;
  }
}


static void prompt_start(void)
{
  display_clear();
  flash_count = 0;
}


static void prompt_start_with_timeout(void)
{
  display_clear();
  flash_count = 0;
  timeout = 154; /* 10 seconds */
}


static void display_set_message(void)
{
  disp3(1, c_S, c_E, c_T);
}


static uint8_t temp1 = 0;
static uint8_t temp2 = 0;
static bit temp_is_leap_year = 0;

static void set_year_init(void)
{
  prompt_start_with_timeout();
  temp1 = current_time.year;
}


static void set_time_draw(uint8_t flash_field)
{
  if (FLASH || flash_field != 0) {
    display_set_message();
  } else {
    disp3(1, 0, 0, 0);
  }
  if (FLASH || flash_field != 1) {
    if (current_settings.display_12hr) {
      set_bcd_byte(5, leading_zero_suppressed(to_12_hour(temp1)));
      display[9] = am_pm_indicator_for_hour(temp1);
    } else {
      set_bcd_byte(5, temp1);
    }
  } else {
    display[5] = display[6] = display[9] = 0;
  }
  if (FLASH || flash_field != 2) {
    set_bcd_byte(7, temp2);
  } else {
    display[7] = display[8] = 0;
  }
  if (pin_is_low(SQW) || flash_field > 0) { display[6] |= sP; }
}


static void set_time_prompt_update(void)
{
  if (TOUCH1_TAP) {
    next_mode = &set_date_prompt;
    return;
  } else if (TOUCH2_TAP) {
    next_mode = &set_hour;
  } else if (TOUCH1_HOLD || TIMEOUT) {
    next_mode = &exit_menu;
    return;
  }
  temp1 = current_time.hour;
  temp2 = current_time.minutes;
  temp_is_leap_year = is_leap_year(current_time.year);
  set_time_draw(0);
}


static void set_hour_update(void)
{
  if (TOUCH1_TAP) {
    next_mode = &set_minute;
    return;
  } else if (TOUCH1_HOLD) {
    next_mode = &exit_menu;
    return;
  } else if (TOUCH2_PRESS|TOUCH2_REPEAT) {
    flash_count = 0;
    temp1 = increment_hour(temp1);
  }
  set_time_draw(1);
}
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

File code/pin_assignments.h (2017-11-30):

#ifndef SRC_PIN_ASSIGNMENTS_H_
#define SRC_PIN_ASSIGNMENTS_H_

#define HV_EN         C5 /* pin 5 */
#define MISO          B4 /* pin 13 */
#define MOSI          C7 /* pin 9 */
#define SCK           B6 /* pin 11 */
#define nRTC_SS       C2 /* pin 14 */
#define nDISP_SS      C4 /* pin 6 */
#define SQW           C6 /* pin 8 */
#define ANODE3        A0 /* pin 19 */
#define ANODE1        A1 /* pin 18 */
#define ANODE0        A2 /* pin 17 */
#define ANODE2        C0 /* pin 16 */
#define ANODE4        C1 /* pin 15 */
#define ANODE012_PORT A
#define ANODE012_PINS (_PBIT(ANODE0)|_PBIT(ANODE1)|_PBIT(ANODE2))
#define ANODE34_PORT  C
#define ANODE34_PINS  (_PBIT(ANODE3)|_PBIT(ANODE4))

#define SENSE1        C3
#define SENSE1_ADC_CH 7
#define SENSE2        A4
#define SENSE2_ADC_CH 3

#endif
